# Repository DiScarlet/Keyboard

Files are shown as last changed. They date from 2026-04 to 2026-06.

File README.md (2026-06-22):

# Duck Keyboard

Why are the Space and Tab keys so big? Completely unnecessary.

We are not accountants. Why should some keys get more space than others?

We demand equality. Equality and ducks.

**52 keys. Zero keycap inequality.**

Ducks, palm trees, and pure summer vibes. Tactile. Compact.

And yes — it quacks when you press it.

Built for minimalists who still want to have fun.

## Features

* 52-key compact layout
* Uniform key sizes with no oversized Space or Tab keys
* Tactile typing experience
* Custom duck-themed design
* Compact footprint for minimalist setups
* Integrated sound effects: every keypress quacks

## Design Philosophy

Most keyboards dedicate excessive space to a handful of keys while the rest compete for room.

The Duck Keyboard rejects keycap inequality. Every key deserves equal treatment. 

## Zine

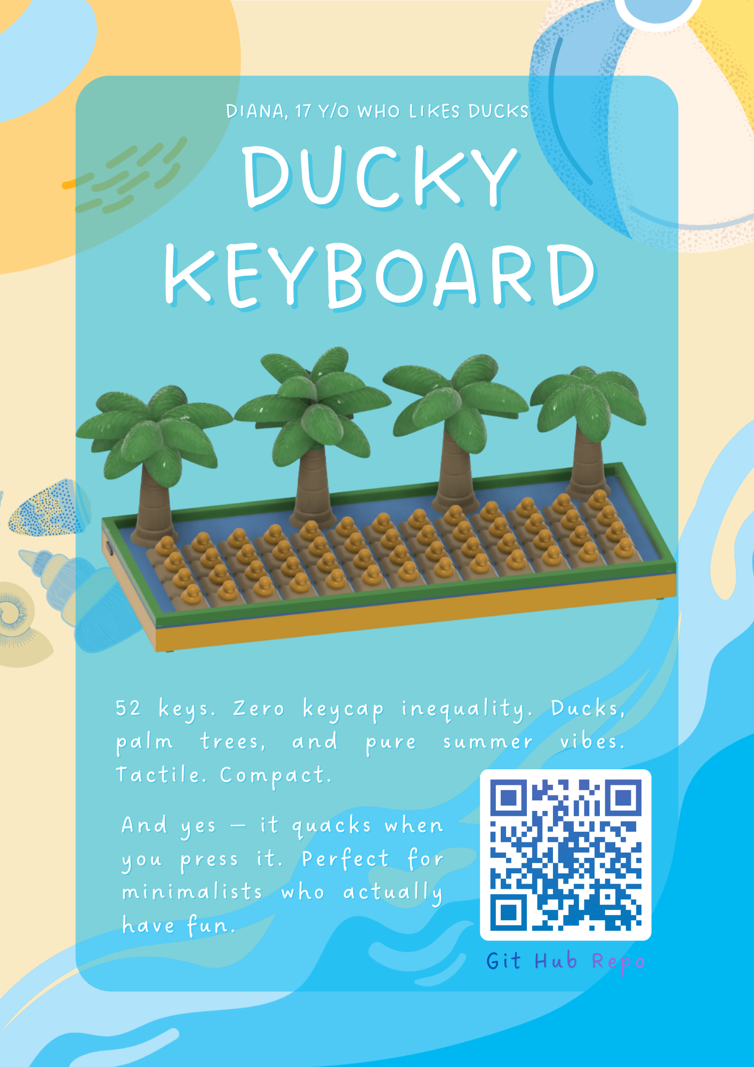
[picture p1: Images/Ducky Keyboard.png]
Zine


## CAD Model and Case

The keyboard case uses Gasket Mounting and was designed to complement the compact layout while maintaining a clean, minimalist appearance.

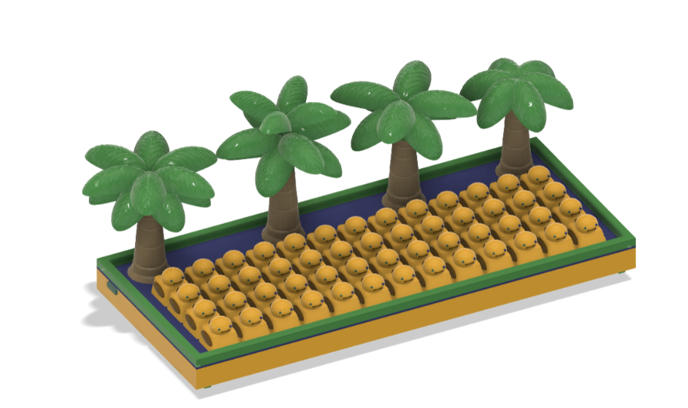
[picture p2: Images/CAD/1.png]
CAD 1
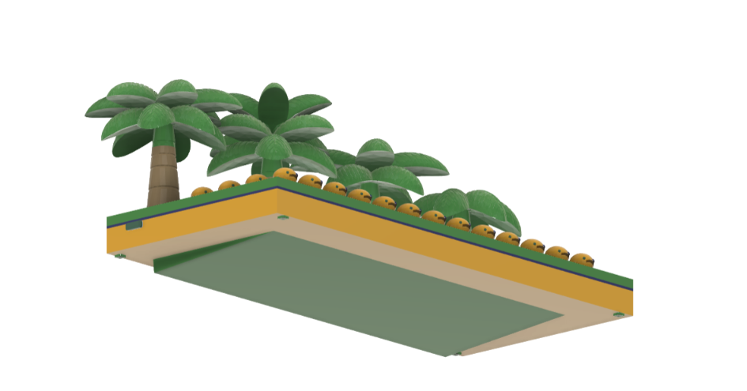
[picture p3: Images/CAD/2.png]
CAD 2
|  |  |

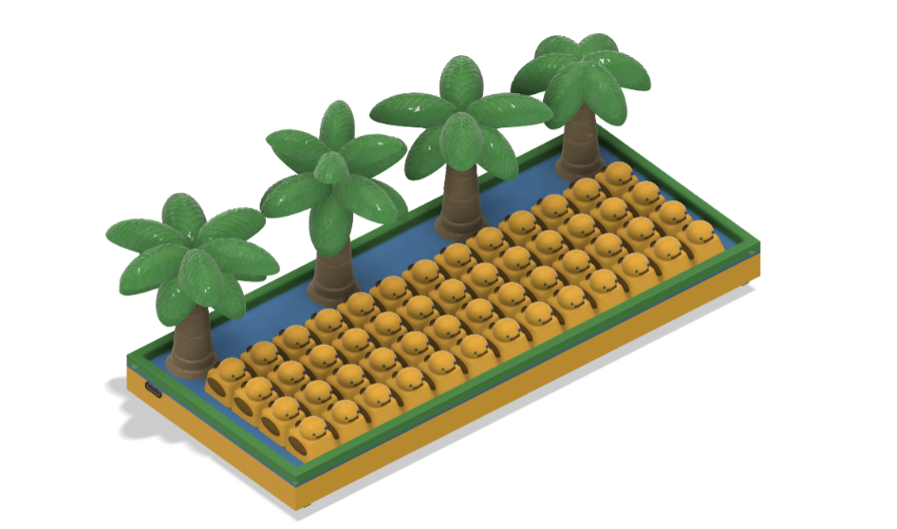
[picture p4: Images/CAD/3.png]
CAD 3
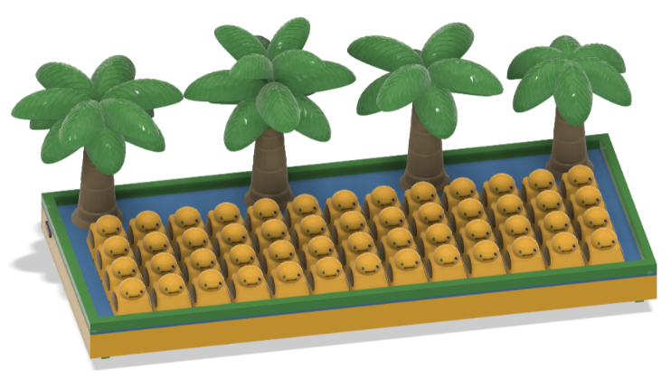
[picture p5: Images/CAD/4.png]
CAD 4
|  |  |

## Electronics

### Schematic

The keyboard electronics are based on a custom schematic designed usinf KiCAD.

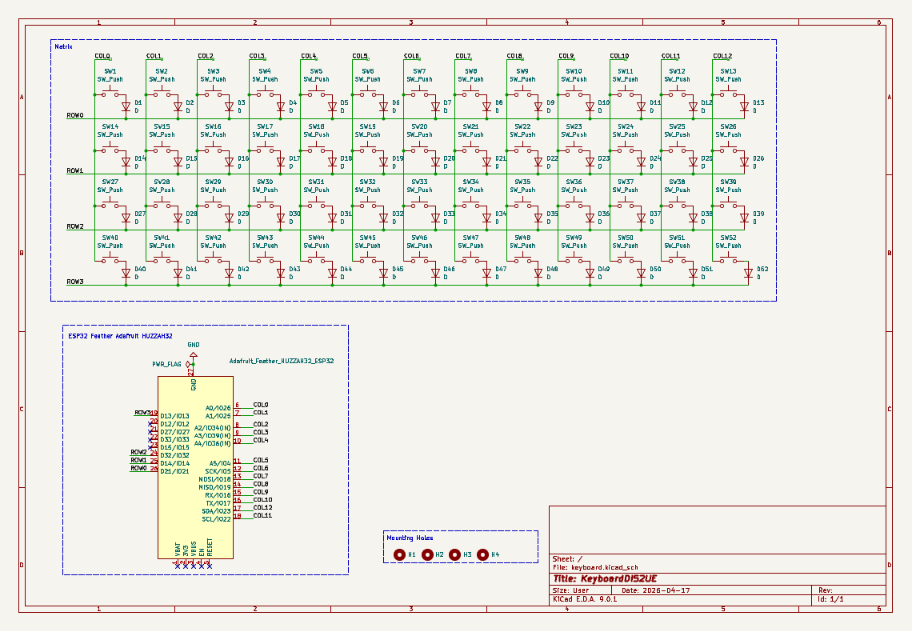
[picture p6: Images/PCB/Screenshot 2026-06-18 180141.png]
Duck Keyboard electronic schematic


### PCB

The custom PCB uses ESP32 Feather.

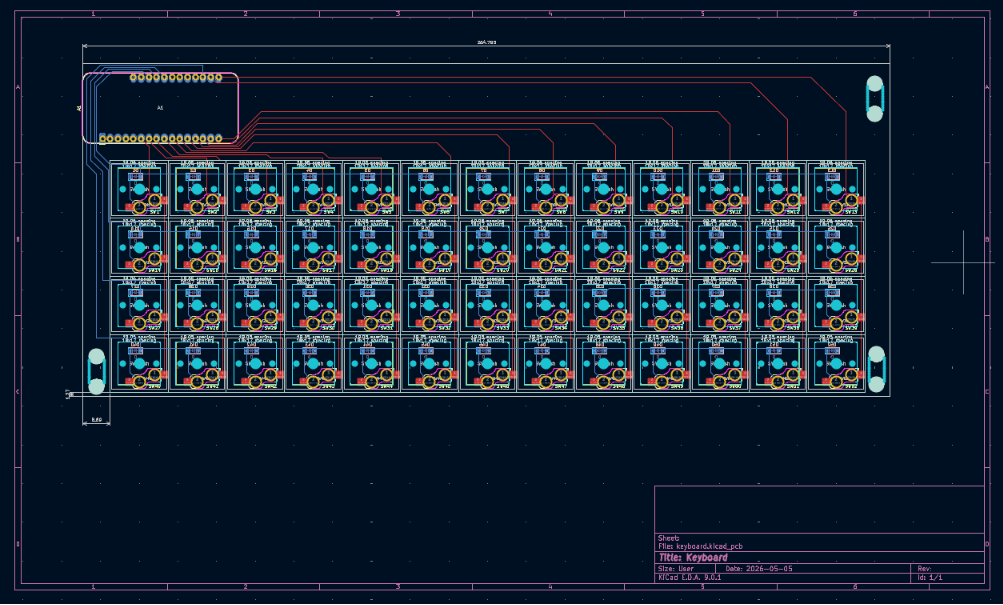
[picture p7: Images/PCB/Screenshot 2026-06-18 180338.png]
PCB layout


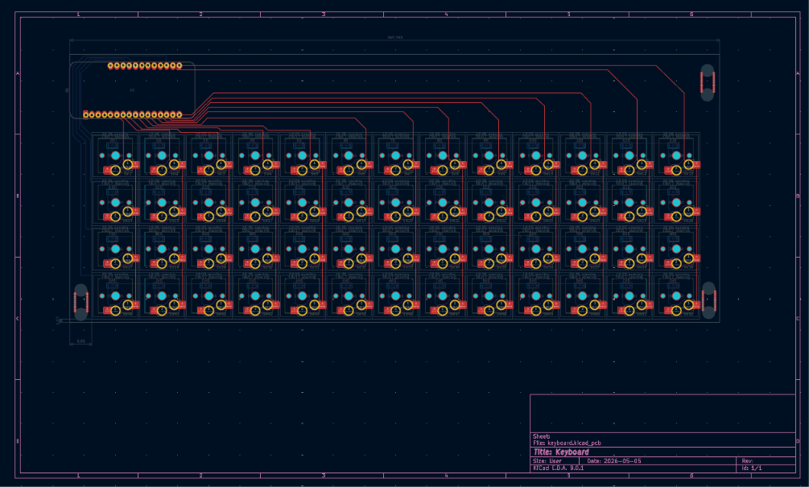
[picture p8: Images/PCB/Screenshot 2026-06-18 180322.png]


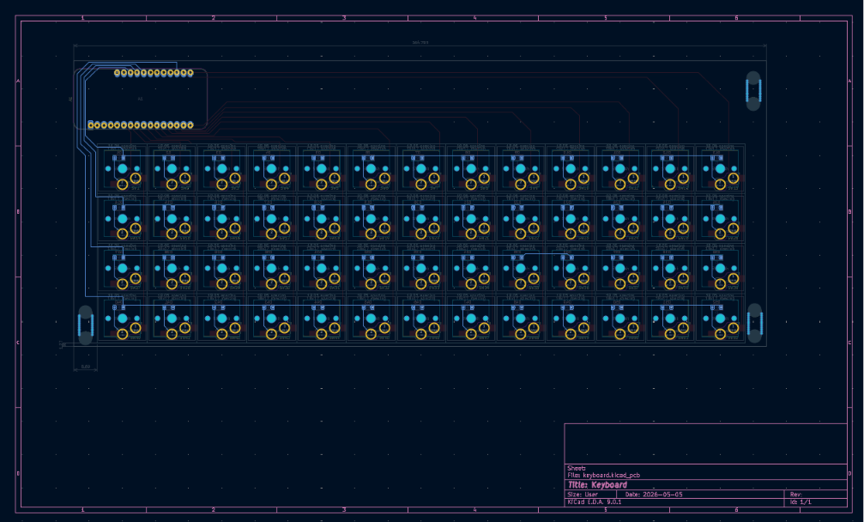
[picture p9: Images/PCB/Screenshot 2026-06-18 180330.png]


#### 3D PCB View

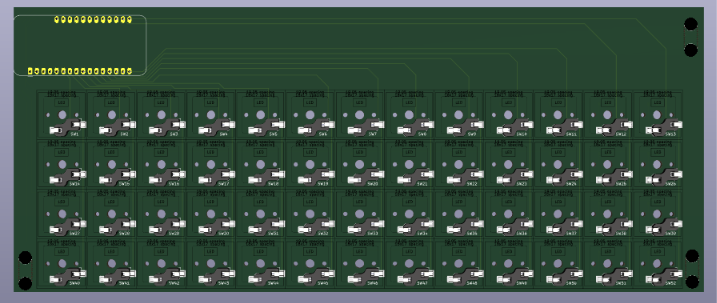
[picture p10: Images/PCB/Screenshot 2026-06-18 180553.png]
3D render of the assembled Duck Keyboard PCB


## Assembly Instructios
1. Flash the ESP32 Feather with the firmware.
2. Solder the hot-swap sockets and the ESP32 Feather to the PCB.
3. Install the switches into the hot-swap sockets.
4. 3D print the top case, bottom case, and keycaps.
5. Place the PCB assembly into the case and secure it using M2 screws.
6. Install the keycaps onto the switches.
7. 3D print the decorative duck and palm tree elements.
8. Attach the decorations to the designated area of the top case using instant glue (cyanoacrylate).
9. (Optional) Print the angle-of-attack wedge to tilt the keyboard toward the user for a more comfortable typing position.

## File Structure

The project layout is:

- `BoM.csv`
- `README.md`
- `CAD_Fusion/`
  - `ESP32-WROOM32-DEVBOARD_DIMENTIONS.f3d`
  - `Downloaded/`
  - `FullAssembly/`
  - `PCB/`
  - `SeparateElements/`
- `Docs/`
  - `ESP32HUZZAH32.txt`
  - `keyboard-layout.json`
  - `Links_to_parts.txt`
- `Hardware/`
  - `keyboard.kicad_sch`
  - `keyboard.kicad_pcb`
  - `keyboard.kicad_pro`
  - `keyboard.kicad_prl`
  - `keyboard-backups/`
  - `Libraries/`
- `Images/`
  - `CAD/`
  - `PCB/`
- `macropad/`
  - `Firmware/`
  - `kicad_care_package/`
  - `kicad_macropad_project/`
- `Symbols/`

## Firmware

Refer to [Firmware ReadMe](Firmware/README.md)

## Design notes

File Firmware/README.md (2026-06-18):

# Duck Keyboard Firmware

This firmware implements a 4x13 keyboard matrix on the ESP32 Feather HUZZAH32 and exposes a BLE HID keyboard device.

## Pin mapping

- Rows: GPIO21, GPIO14, GPIO32, GPIO13
- Columns: GPIO26, GPIO25, GPIO34, GPIO39, GPIO36, GPIO4, GPIO5, GPIO18, GPIO19, GPIO16, GPIO17, GPIO22, GPIO23

## Build instructions

1. Install the ESP32 Arduino core for the Arduino IDE or Visual Studio Code PlatformIO.
2. Install the `ESP32 BLE Keyboard` library.
3. Open `Firmware/DuckKeyboard.ino`.
4. Select the `Adafruit ESP32 Feather` board or equivalent ESP32 board.
5. Upload the sketch.

## Keymap

The default keymap is arranged as a 4x13 layout:

- Row 0: ESC, 1, 2, 3, 4, 5, 6, 7, 8, 9, 0, -, =
- Row 1: TAB, Q, W, E, R, T, Y, U, I, O, P, [, ]
- Row 2: CAPS LOCK, A, S, D, F, G, H, J, K, L, ;, ', ENTER
- Row 3: LEFT SHIFT, Z, X, C, V, B, N, M, ,, ., /, SPACE, BACKSPACE

## Notes

- If you want a custom layout, edit the `keymap` table in `DuckKeyboard.ino`.
- The keyboard uses internal pull-ups on the column pins and drives one row low at a time.
- Audio/quack effects are not implemented in this initial firmware.

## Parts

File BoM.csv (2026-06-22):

Reference | Part | Qty | Purchase Link | Unit Price (USD) | Total (USD)
A1 | Adafruit Feather HUZZAH32 ESP32 | 1 | https://www.adafruit.com/product/3405 | 19.95(Already Own)
D1-D52 | SOD-123 Switching Diode | 52 | https://www.aliexpress.com/item/1005007160279747.html?curPageLogUid=t1wPKpMvt4MG | 0.03 | 3.20(Already Own)
SW1-SW52 | Kailh Choc V1 Switch | 52 | https://www.aliexpress.com/item/1005005184851984.html?curPageLogUid=PxHRaeYuQh2d | 0.55 | 28.60
SW1-SW52 | Kailh Low Profile Keyboard Switches Hot-swap | 70 | https://www.aliexpress.com/item/1005011887359428.html?curPageLogUid=OJG1eP1OqVjT | 11.88
- | 3D Printing | - | Local(Price for the filament) | 5(Already Own)
TOTAL |  |  |  |  | 68.63

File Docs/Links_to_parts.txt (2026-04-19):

Links to parts:

- Diodes: 1N4148W SOD123 (100 pcs) $1.70
https://pl.aliexpress.com/item/1005007160563285.html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

- Resistors(2 * 100 pcs) $0.46 * 2 = $0.92: 
0805 SMD 820k 
https://pl.aliexpress.com/item/1005009040750970.html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
0805 SMD 2M	
https://pl.aliexpress.com/item/1005009040750970.html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

- Switches: Kailh Low profile Choc switch 1350 RGB (30pcs FOR NOW!) $17.40
https://pl.aliexpress.com/item/1005005883472162.html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

- FIND KEYCAPS!!!!

- Microcontroller: XIAO BLE nRF52840 US $11.71 (no pins BTW!)
https://pl.aliexpress.com/item/1005006988954136.html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

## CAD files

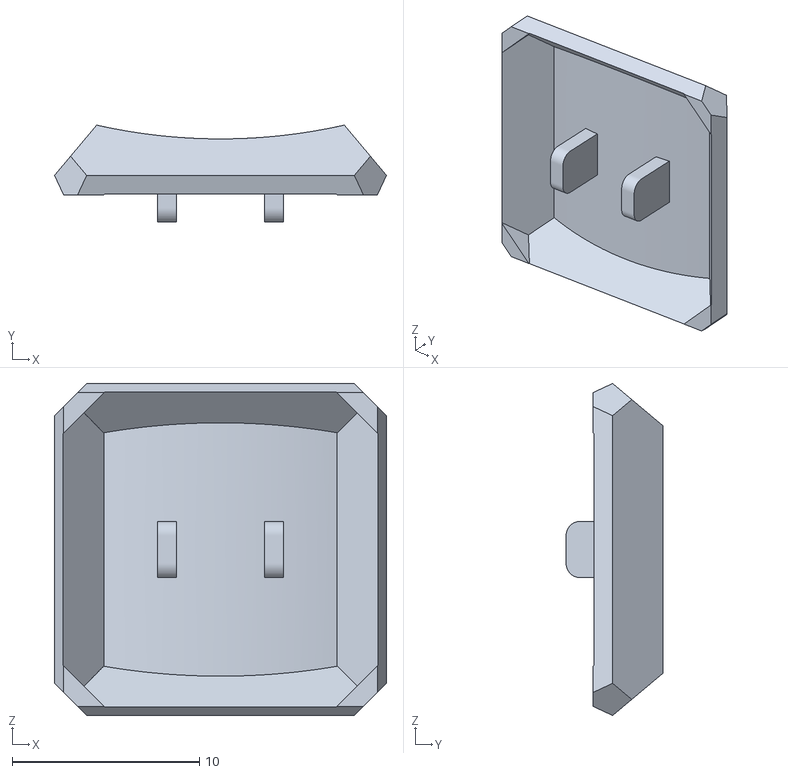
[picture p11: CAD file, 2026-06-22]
CAD_Fusion/Downloaded/Keycaps/Kailh Low Profile Keycap v14.stl
17.7 x 5.17 x 17.7

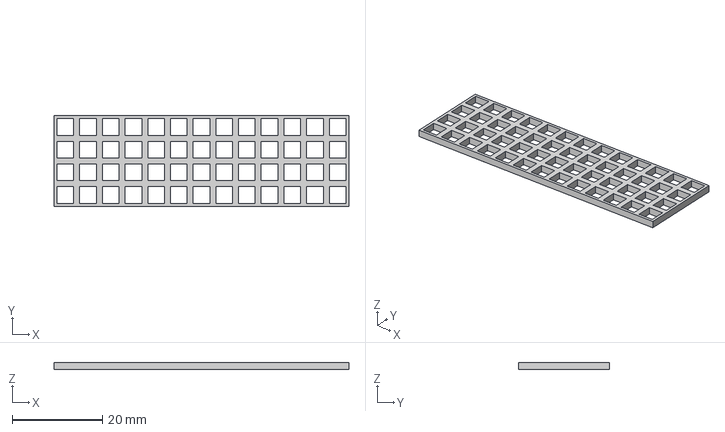
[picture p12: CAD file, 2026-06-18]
CAD_Fusion/SeparateElements/Layout.stp
65.5 x 20.2 x 1.60 mm

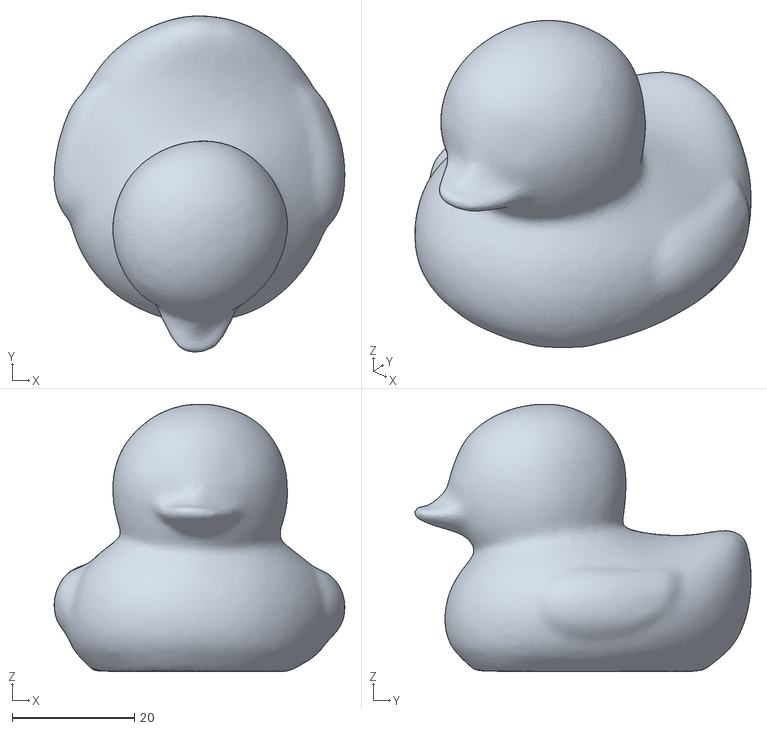
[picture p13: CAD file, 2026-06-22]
CAD_Fusion/Downloaded/Keycaps/44mm Height Rubber Duck.stl
47.6 x 55.0 x 43.8

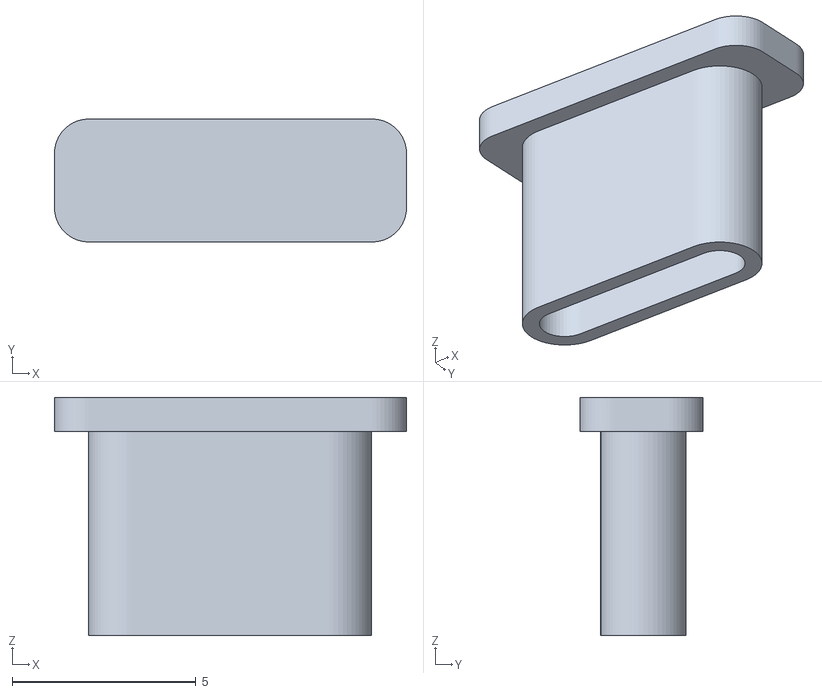
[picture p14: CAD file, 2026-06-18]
CAD_Fusion/Downloaded/USB-C+Dust+cap+v3.stl
9.59 x 3.35 x 6.50

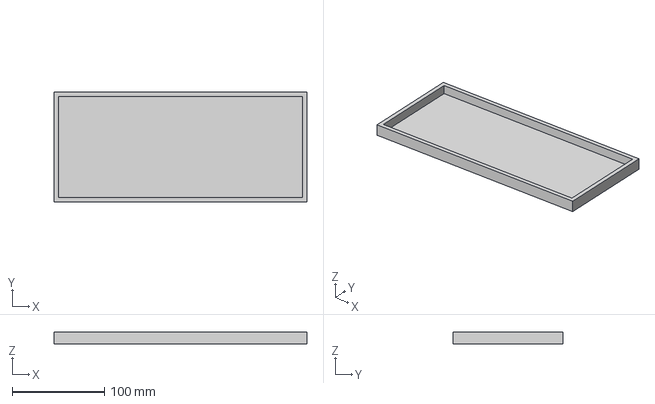
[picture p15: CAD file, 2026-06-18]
CAD_Fusion/SeparateElements/BottomCase.stp
274.8 x 119.2 x 13.3 mm

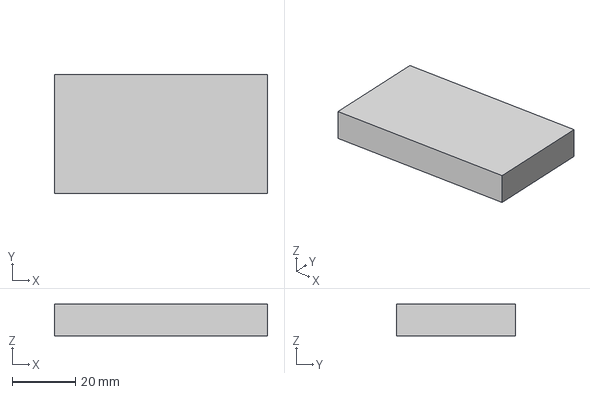
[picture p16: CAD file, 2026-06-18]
CAD_Fusion/SeparateElements/TopCover.stp
67.2 x 37.7 x 10.0 mm

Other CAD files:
CAD_Fusion/FullAssembly/KeyboardAssembly.step
CAD_Fusion/PCB/keyboard.step
CAD_Fusion/SeparateElements/Additional/DuckKeyCap.stp
CAD_Fusion/SeparateElements/Decor/palmtree_2x4.stp
Hardware/Custom/3D/Kailh Choc Low Profile Switch.step
CAD_Fusion/SeparateElements/Additional/USB-C+Dust+cap+v3.stp
CAD_Fusion/SeparateElements/Decor/palmtree_1x6.stp
CAD_Fusion/Downloaded/USB-C.STEP
CAD_Fusion/SeparateElements/Decor/palmtree_3x4.stp
CAD_Fusion/SeparateElements/Decor/palmtree_2x6.stp
CAD_Fusion/Downloaded/M2 x 0.4mm Thread 16mm LONG SOCKET HEAD CAP SCREW.STEP
CAD_Fusion/ESP32-WROOM32-DEVBOARD_DIMENTIONS.f3d
CAD_Fusion/FullAssembly/KeyboardAssemblyF3Z.f3z

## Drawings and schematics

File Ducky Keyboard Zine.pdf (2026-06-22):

# DUCKY KEYBOARD

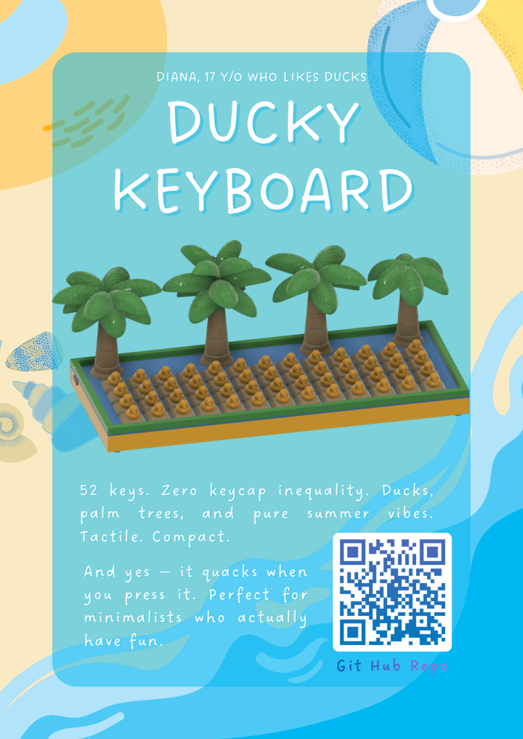
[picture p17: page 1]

DIANA, 17 Y/O WHO LIKES DUCKS

52 keys. Zero keycap inequality. Ducks,
palm trees, and pure summer vibes.
Tactile. Compact.
And yes — it quacks when
you press it. Perfect for
minimalists who actually
have fun.

Git Hub Repo

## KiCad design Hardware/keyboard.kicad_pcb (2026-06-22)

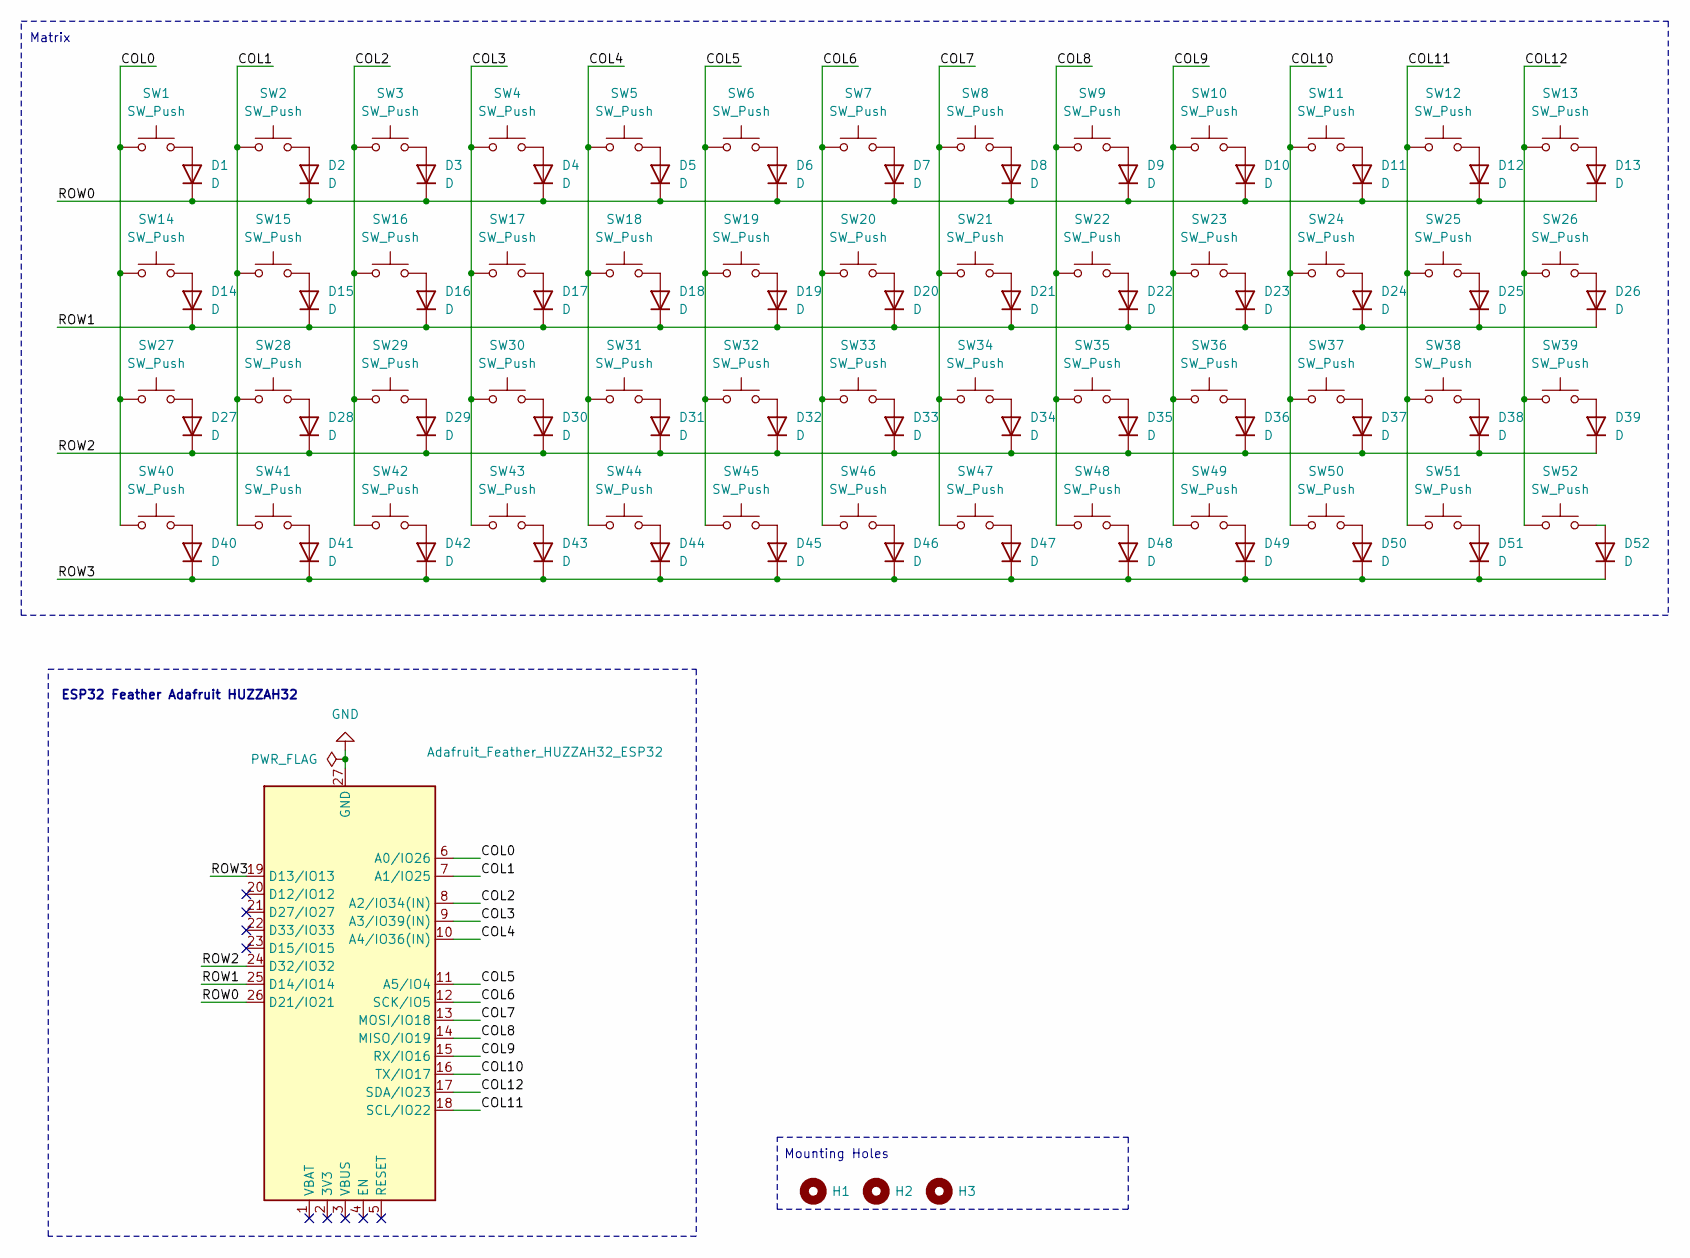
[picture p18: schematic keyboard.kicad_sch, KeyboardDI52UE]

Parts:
A1: Adafruit_Feather_HUZZAH32_ESP32; Adafruit_Feather
D1, D2, D3, D4, D5, D6, D7, D8, D9, D10, D11, D12, D13, D14, D15, D16, D17, D18, D19, D20, D21, D22, D23, D24, D25, D26, D27, D28, D29, D30, D31, D32, D33, D34, D35, D36, D37, D38, D39, D40, D41, D42, D43, D44, D45, D46, D47, D48, D49, D50, D51, D52: D; D_SOD-123
H1, H2, H3: MountingHole; MountingHole_2.1mm
SW1, SW2, SW3, SW4, SW5, SW6, SW7, SW8, SW9, SW10, SW11, SW12, SW13, SW14, SW15, SW16, SW17, SW18, SW19, SW20, SW21, SW22, SW23, SW24, SW25, SW26, SW27, SW28, SW29, SW30, SW31, SW32, SW33, SW34, SW35, SW36, SW37, SW38, SW39, SW40, SW41, SW42, SW43, SW44, SW45, SW46, SW47, SW48, SW49, SW50, SW51, SW52: SW_Push; SW_choc_v1_HS_CPG135001S30_1u

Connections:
/COL0: A1.6 (A0/IO26), SW1.1, SW14.1, SW27.1, SW40.1
/COL1: A1.7 (A1/IO25), SW2.1, SW15.1, SW28.1, SW41.1
/COL2: A1.8 (A2/IO34(IN)), SW3.1, SW16.1, SW29.1, SW42.1
/COL3: A1.9 (A3/IO39(IN)), SW4.1, SW17.1, SW30.1, SW43.1
/COL4: A1.10 (A4/IO36(IN)), SW5.1, SW18.1, SW31.1, SW44.1
/COL5: A1.11 (A5/IO4), SW6.1, SW19.1, SW32.1, SW45.1
/COL6: A1.12 (SCK/IO5), SW7.1, SW20.1, SW33.1, SW46.1
/COL7: A1.13 (MOSI/IO18), SW8.1, SW21.1, SW34.1, SW47.1
/COL8: A1.14 (MISO/IO19), SW9.1, SW22.1, SW35.1, SW48.1
/COL9: A1.15 (RX/IO16), SW10.1, SW23.1, SW36.1, SW49.1
/COL10: A1.16 (TX/IO17), SW11.1, SW24.1, SW37.1, SW50.1
/COL11: A1.18 (SCL/IO22), SW12.1, SW25.1, SW38.1, SW51.1
/COL12: A1.17 (SDA/IO23), SW13.1, SW26.1, SW39.1, SW52.1
/ROW0: A1.26 (D21/IO21), D1.1 (K), D2.1 (K), D3.1 (K), D4.1 (K), D5.1 (K), D6.1 (K), D7.1 (K), D8.1 (K), D9.1 (K), D10.1 (K), D11.1 (K), D12.1 (K), D13.1 (K)
/ROW1: A1.25 (D14/IO14), D14.1 (K), D15.1 (K), D16.1 (K), D17.1 (K), D18.1 (K), D19.1 (K), D20.1 (K), D21.1 (K), D22.1 (K), D23.1 (K), D24.1 (K), D25.1 (K), D26.1 (K)
/ROW2: A1.24 (D32/IO32), D27.1 (K), D28.1 (K), D29.1 (K), D30.1 (K), D31.1 (K), D32.1 (K), D33.1 (K), D34.1 (K), D35.1 (K), D36.1 (K), D37.1 (K), D38.1 (K), D39.1 (K)
/ROW3: A1.19 (D13/IO13), D40.1 (K), D41.1 (K), D42.1 (K), D43.1 (K), D44.1 (K), D45.1 (K), D46.1 (K), D47.1 (K), D48.1 (K), D49.1 (K), D50.1 (K), D51.1 (K), D52.1 (K)
GND: A1.27 (GND)
unnamed: D1.2 (A), SW1.2
unnamed: D2.2 (A), SW2.2
unnamed: D3.2 (A), SW3.2
unnamed: D4.2 (A), SW4.2
unnamed: D5.2 (A), SW5.2
unnamed: D6.2 (A), SW6.2
unnamed: D7.2 (A), SW7.2
unnamed: D8.2 (A), SW8.2
unnamed: D9.2 (A), SW9.2
unnamed: D10.2 (A), SW10.2
unnamed: D11.2 (A), SW11.2
unnamed: D12.2 (A), SW12.2
unnamed: D13.2 (A), SW13.2
unnamed: D14.2 (A), SW14.2
unnamed: D15.2 (A), SW15.2
unnamed: D16.2 (A), SW16.2
unnamed: D17.2 (A), SW17.2
unnamed: D18.2 (A), SW18.2
unnamed: D19.2 (A), SW19.2
unnamed: D20.2 (A), SW20.2
unnamed: D21.2 (A), SW21.2
unnamed: D22.2 (A), SW22.2
unnamed: D23.2 (A), SW23.2
unnamed: D24.2 (A), SW24.2
unnamed: D25.2 (A), SW25.2
unnamed: D26.2 (A), SW26.2
unnamed: D27.2 (A), SW27.2
unnamed: D28.2 (A), SW28.2
unnamed: D29.2 (A), SW29.2
unnamed: D30.2 (A), SW30.2
unnamed: D31.2 (A), SW31.2
unnamed: D32.2 (A), SW32.2
unnamed: D33.2 (A), SW33.2
unnamed: D34.2 (A), SW34.2
unnamed: D35.2 (A), SW35.2
unnamed: D36.2 (A), SW36.2
unnamed: D37.2 (A), SW37.2
unnamed: D38.2 (A), SW38.2
unnamed: D39.2 (A), SW39.2
unnamed: D40.2 (A), SW40.2
unnamed: D41.2 (A), SW41.2
unnamed: D42.2 (A), SW42.2
unnamed: D43.2 (A), SW43.2
unnamed: D44.2 (A), SW44.2
unnamed: D45.2 (A), SW45.2
unnamed: D46.2 (A), SW46.2
unnamed: D47.2 (A), SW47.2
unnamed: D48.2 (A), SW48.2
unnamed: D49.2 (A), SW49.2
unnamed: D50.2 (A), SW50.2
unnamed: D51.2 (A), SW51.2
unnamed: D52.2 (A), SW52.2

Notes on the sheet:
ESP32 Feather Adafruit HUZZAH32
Matrix
Mounting Holes

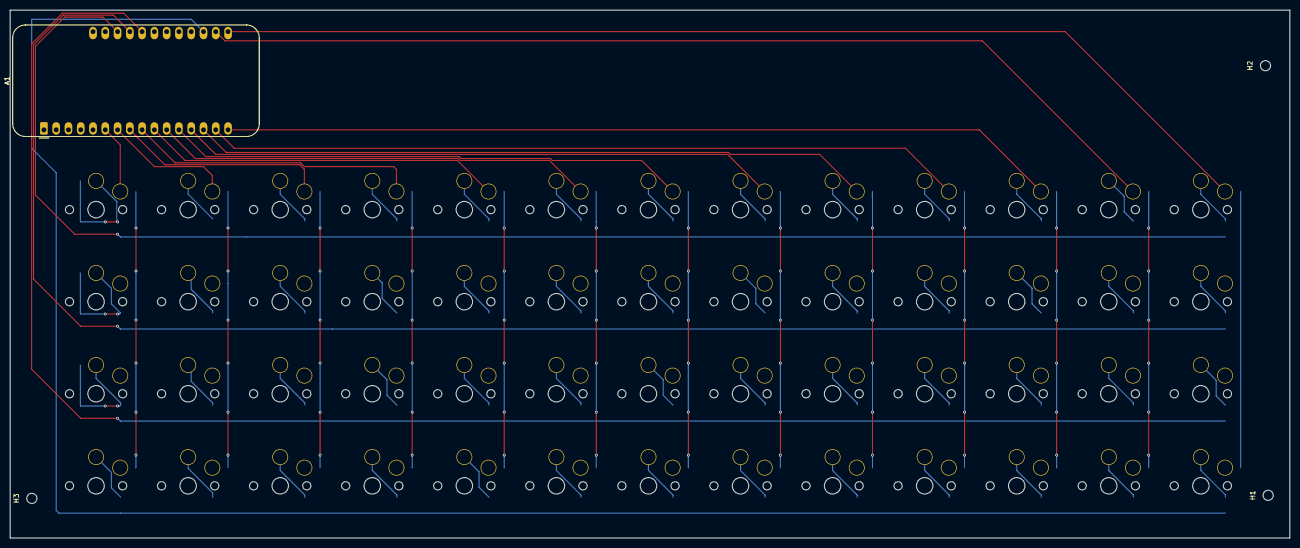
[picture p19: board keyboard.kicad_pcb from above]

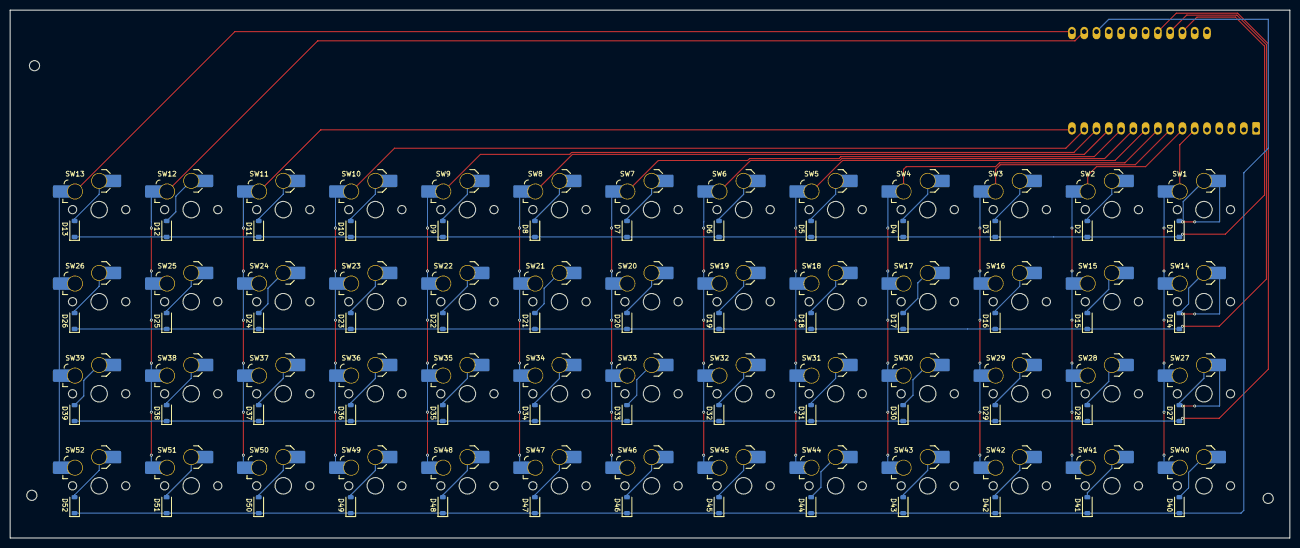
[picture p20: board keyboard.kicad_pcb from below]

Board: 2 copper layers, 264.8 x 109.2 mm, 108 parts (104 on the bottom side), 69 nets.

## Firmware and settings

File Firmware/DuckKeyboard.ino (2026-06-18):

#include <Arduino.h>
#include <BleKeyboard.h>

const uint8_t rowPins[] = {21, 14, 32, 13};
const uint8_t colPins[] = {26, 25, 34, 39, 36, 4, 5, 18, 19, 16, 17, 22, 23};
const uint8_t rowCount = sizeof(rowPins) / sizeof(rowPins[0]);
const uint8_t colCount = sizeof(colPins) / sizeof(colPins[0]);

const uint8_t keymap[rowCount][colCount] = {
  {KEY_ESC, '1', '2', '3', '4', '5', '6', '7', '8', '9', '0', '-', '='},
  {KEY_TAB, 'q', 'w', 'e', 'r', 't', 'y', 'u', 'i', 'o', 'p', '[', ']'},
  {KEY_CAPS_LOCK, 'a', 's', 'd', 'f', 'g', 'h', 'j', 'k', 'l', ';', '\'', KEY_RETURN},
  {KEY_LEFT_SHIFT, 'z', 'x', 'c', 'v', 'b', 'n', 'm', ',', '.', '/', KEY_SPACE, KEY_BACKSPACE}
};

bool previousState[rowCount][colCount] = {};
BleKeyboard bleKeyboard("Duck Keyboard", "Duck Keyboard", 100);

void setupMatrix() {
  for (uint8_t r = 0; r < rowCount; ++r) {
    pinMode(rowPins[r], OUTPUT);
    digitalWrite(rowPins[r], HIGH);
  }

  for (uint8_t c = 0; c < colCount; ++c) {
    pinMode(colPins[c], INPUT_PULLUP);
  }
}

void scanMatrix(bool matrix[rowCount][colCount]) {
  for (uint8_t r = 0; r < rowCount; ++r) {
    digitalWrite(rowPins[r], LOW);
    delayMicroseconds(30);

    for (uint8_t c = 0; c < colCount; ++c) {
      matrix[r][c] = digitalRead(colPins[c]) == LOW;
    }

    digitalWrite(rowPins[r], HIGH);
  }
}

bool matrixChanged(const bool current[rowCount][colCount]) {
  for (uint8_t r = 0; r < rowCount; ++r) {
    for (uint8_t c = 0; c < colCount; ++c) {
      if (current[r][c] != previousState[r][c]) {
        return true;
      }
    }
  }
  return false;
}

void sendKeys(const bool current[rowCount][colCount]) {
  bleKeyboard.releaseAll();

  for (uint8_t r = 0; r < rowCount; ++r) {
    for (uint8_t c = 0; c < colCount; ++c) {
      if (current[r][c]) {
        bleKeyboard.press(keymap[r][c]);
      }
    }
  }
}

void setup() {
  Serial.begin(115200);
  setupMatrix();
  bleKeyboard.begin();
}

void loop() {
  bool currentState[rowCount][colCount] = {};
  scanMatrix(currentState);

  if (bleKeyboard.isConnected() && matrixChanged(currentState)) {
    sendKeys(currentState);
    memcpy(previousState, currentState, sizeof(previousState));
  } else if (!bleKeyboard.isConnected()) {
    memset(previousState, 0, sizeof(previousState));
  }

  delay(10);
}

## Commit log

2026-04-19 Added links to parts
    [keyboard.kicad_pcb, side.kicad_sch]
2026-04-19 Changed keyboard layout to 4*13
    [keyboard.kicad_sch, side.kicad_sch]
2026-04-22 Added ESP32 devboard dimentions
    [ESP32-WROOM32-DEVBOARD_DIMENTIONS.f3d]
2026-04-22 Reorganized the repo
    [keyboard.kicad_pcb, keyboard.kicad_sch, side.kicad_sch]
2026-04-22 Replaced XIAO with ESP32 devoard
    [keyboard.kicad_sch]
2026-04-24 Swiched to ESP32 Feather Adafruit HUZZAH32
    [keyboard.kicad_sch]
2026-04-25 Resolved ERC errors/warnings
    [keyboard.kicad_sch]
2026-05-05 Added part 1 of PCB
    [keyboard.csv, keyboard.kicad_pcb, keyboard.kicad_sch]
2026-06-01 Added hardware source files and configure gitignore
    [keyboard.kicad_pcb, keyboard.kicad_sch]
2026-06-01 Moved ESP to the left for charging
    [keyboard.kicad_pcb]
2026-06-18 Finihed Case Design
    [BoM.csv, BottomCase.stp, DESchoc-mid-1u.stl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]
2026-06-18 Added Zine, updated BoM
    [BoM.csv]
2026-06-22 Fixed model by the requirements check
    [44mm Height Rubber Duck.stl, BoM.csv, DESchoc-mid-1u.stl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]
